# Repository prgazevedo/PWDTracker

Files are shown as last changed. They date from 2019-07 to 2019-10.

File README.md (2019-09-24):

# PWDTracker
A prototype for geo location using Lora

## Build - Current Build options

Requires following libraries:
 - PubsubClient for MQTT: https://github.com/knolleary/pubsubclient/releases/tag/v2.7
 - ArduinoJson for MQTT: https://arduinojson.org/?utm_source=meta&utm_medium=library.properties
 - Autoconnect for Wifi: https://hieromon.github.io/AutoConnect/index.html
 - TinyGpsPlus for GPS: https://github.com/mikalhart/TinyGPS
 - SSD1306 for OLED: https://github.com/ThingPulse/esp8266-oled-ssd1306
 - Lora radio by Sandeep: https://github.com/sandeepmistry/arduino-LoRa
 - MQTT by Joël Gähwiler: https://github.com/256dpi/arduino-mqtt
 - TLS-enabled web server for the ESP32 using the Arduino core: https://github.com/fhessel/esp32_https_server
  - SimpleList: https://github.com/blackhack/ArduLibraries/tree/master/SimpleList
Board library:
 - Heltec: https://github.com/HelTecAutomation/Heltec_ESP32
For low power uses: https://github.com/espressif/esp-idf/blob/master/components/esp32/include/esp_sleep.h
In _Definitions.h change _ROLE to either 0 or 1 //SENDER=0 RECEIVER=1

## Upload Current Bin files
 - See binary files to upload to modules in [PWDTracker/bin](https://github.com/prgazevedo/PWDTracker/tree/master/bin)
 - Note: to upload: 1- turn on verbose output (in Preferences). 2- Make a dummy arduino file and during upload and watch for a command in the end with AVRDUDE in it along with the path of hex/bin file. 3- just copy paste & run the same command in CommandLine replacing the bin file with the one downloaded from here.

## Current Used Hardware
- Upload this code via Serial to Heltec Wifi Lora: https://heltec.org/project/wifi-lora-32/ can buy it here: https://www.amazon.es/gp/product/B076T28KWG
- Use a GPS module to connect (Rx<-->TX) to pins 22/23 on Heltec: Rx-Heltec_Pin22 to Tx pin on GPS and Rx-Heltec_Pin23 to  Rx pin on GPS . ![GPS connectors] (https://github.com/prgazevedo/PWDTracker/blob/master/images/GT-U7_connections_back.png)
Buy similar GPS modules at: https://www.aliexpress.com/item/32828934753.html or https://www.amazon.es/gp/product/B0783H7BLW
An example of soldering connections for GPS to Heltec module is
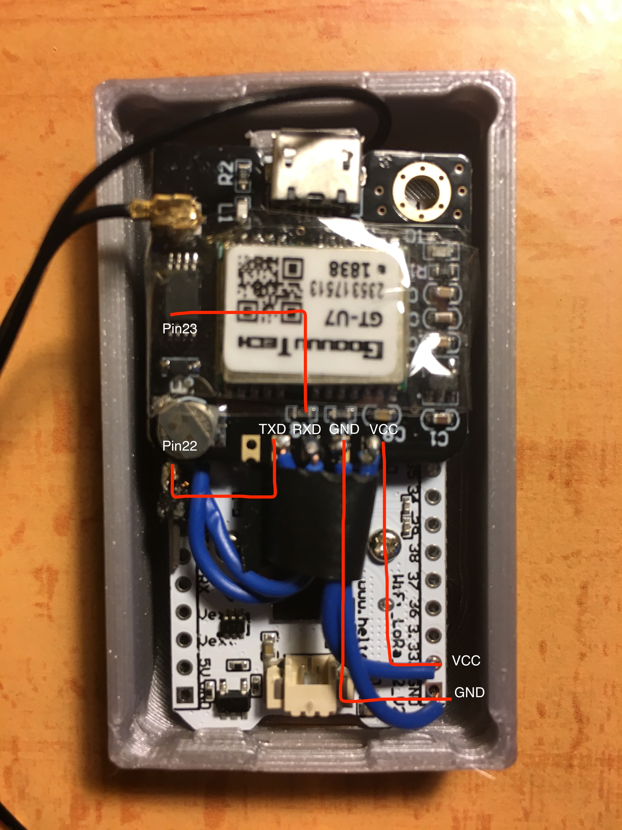
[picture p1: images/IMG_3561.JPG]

- Use ipex connector for Lora devices(DO NOT POWER UP WITHOUT ANTENNA CONNECTED)
- Use a good GPS antenna for precision outdoors: https://www.amazon.es/gp/product/B01BML4XMQ
- Use a Ipex to SMA converter: https://www.amazon.es/gp/product/B07G5H6WH3
- Use the following batteries to Sender (Li-Po 3.7V 850mAh 6x30x48mm):https://mauser.pt/catalog/product_info.php?products_id=035-9016 and Receiver (Li-Po 3.7V 450mAh 5x22x48mm): https://mauser.pt/catalog/product_info.php?products_id=035-9008
- Connect the batteries and the Switch to Heltec Raster PicoBlade connector: https://mauser.pt/catalog/product_info.php?products_id=035-0050
- Solder the + contact of the battery and of Heltec connector to the switch: https://mauser.pt/catalog/product_info.php?products_id=010-1218
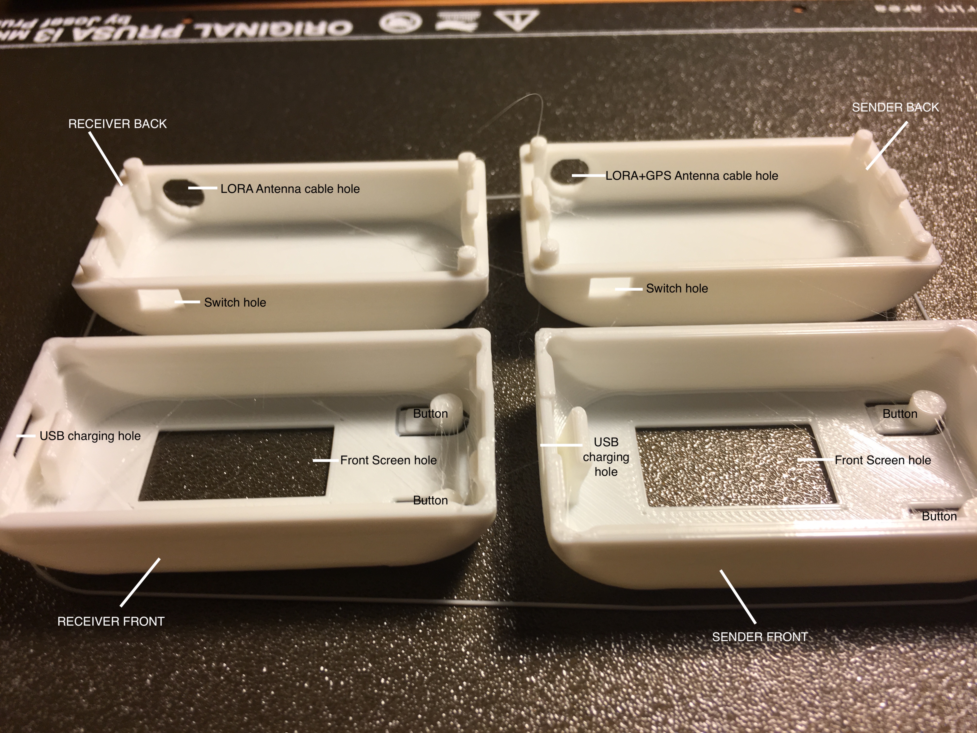
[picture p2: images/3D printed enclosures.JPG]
printed enclosures
- 3d print the enclosures using the files at (https://github.com/prgazevedo/PWDTracker/tree/master/enclosures). An example of the printed enclosures is 
An example of the full setup is
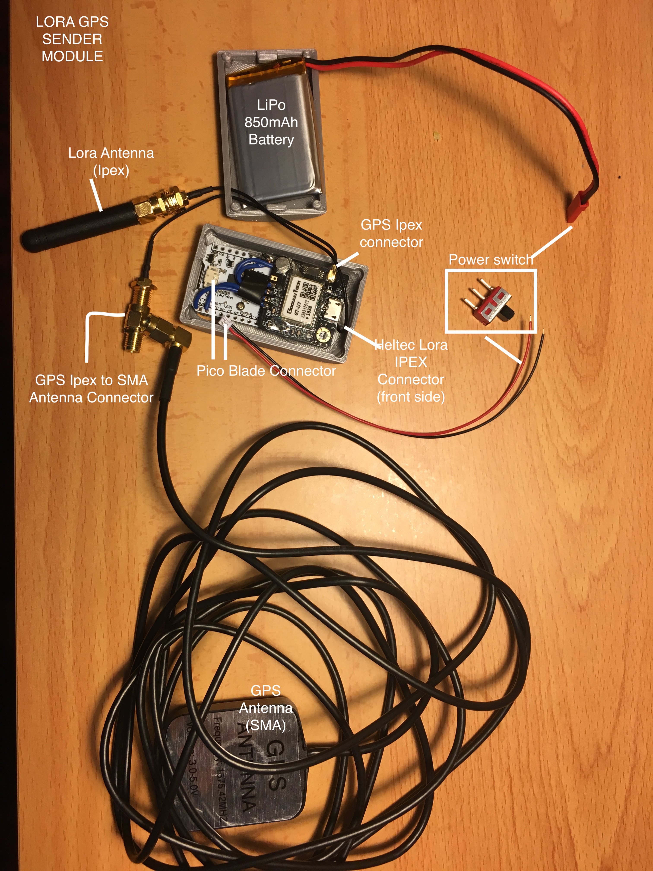
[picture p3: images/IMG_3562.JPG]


## Current Usage
 - Power up both devices (power to all via USB)
 - Check that both devices boot up and present correct GPS data in OLED display
 - Connect to receiver IP via http to view the location of sender device
 - View latitude and longitude of sender in the cloud: mqtt://broker.hivemq.com:1883 Topic:owntracks/PWD/#
 - Download the App at AppStore(https://apps.apple.com/us/app/owntracks/id692424691) or GooglePlay (https://play.google.com/store/apps/details?id=org.owntracks.android&hl=en)

## TODO
 - ~~Add webserver to configure options~~ (DONE)
 - Add discovery of wireless LAN tracking
 - Remove all String usage (avoid) and use CString or Char*
 - Optimize Sender code to reduce power consumption
 - Setup and test autoconnect functionality in Receiver

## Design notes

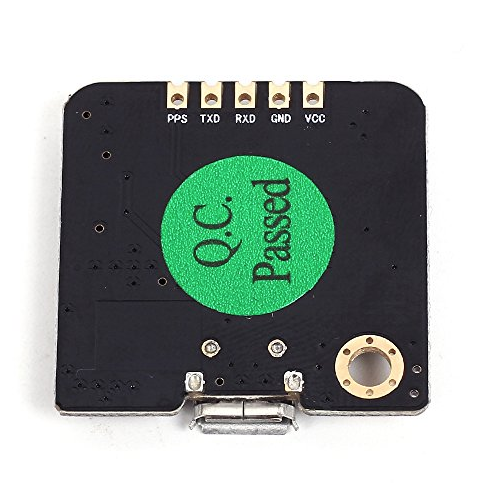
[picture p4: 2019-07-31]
images/GT-U7_connections_back.png

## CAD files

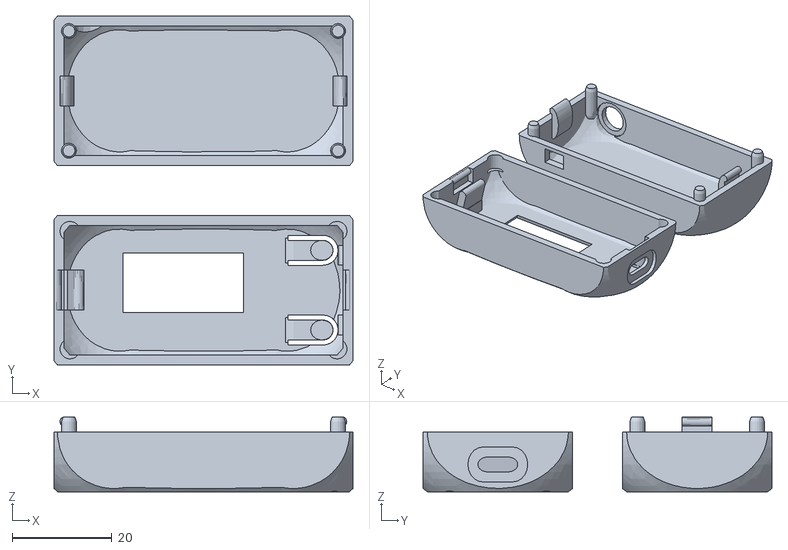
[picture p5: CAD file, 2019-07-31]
enclosures/Lora-Proto-with_switch_receiver_v1.stl
60.0 x 70.0 x 15.0

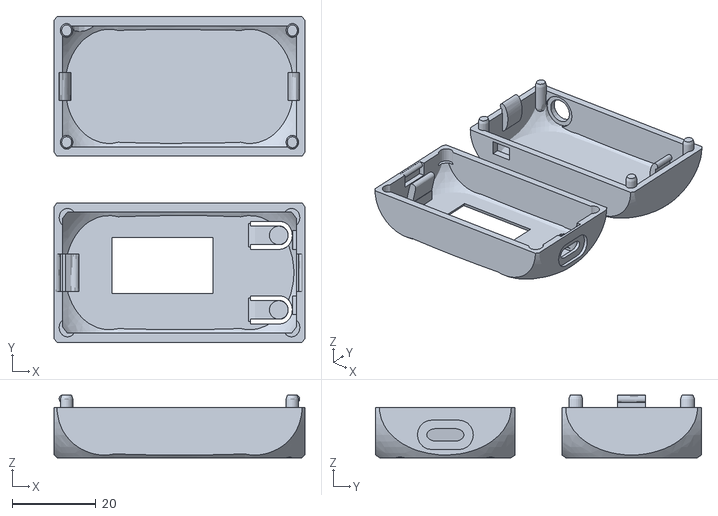
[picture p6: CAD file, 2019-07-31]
enclosures/Lora-Proto-with_switch_sender_v1.stl
60.0 x 78.0 x 15.0

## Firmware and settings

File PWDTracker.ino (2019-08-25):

/*
 * Copyright 2018 Pedro Azevedo (prgazevedo@gmail.com)
 * and other contributors as indicated by the @author tags.
 * 
 * Based on: 
 * https://github.com/mikalhart/TinyGPSPlus
 * https://github.com/Heltec-Aaron-Lee/WiFi_Kit_series
 * https://github.com/sandeepmistry/arduino-LoRa
 **********************************************************************
 * Licensed under the Apache License, Version 2.0 (the "License");
 * you may not use this file except in compliance with the License.
 * You may obtain a copy of the License at
 *
 *    http://www.apache.org/licenses/LICENSE-2.0
 *
 * Unless required by applicable law or agreed to in writing, software
 * distributed under the License is distributed on an "AS IS" BASIS,
 * WITHOUT WARRANTIES OR CONDITIONS OF ANY KIND, either express or implied.
 * See the License for the specific language governing permissions and
 * limitations under the License.
 */

#include <SPI.h> //Serial Comms Lib
#include <LoRa.h> //Lora Comms Lib
#include "SSD1306.h" //OLED display Lib
#include "_CStrings.h" //CString mem reduction code
#include "_SerialCode.h" //Serial lib
#include "_oledCode.h" //OLED code
#include "_GPSCode.h" //GPS code
#include "_LoraCode.h" //Lora Code
#include "_Definitions.h"
#include "_Global.h"
#include "_WifiManager.h"
#include "_File.h"
#include "_MQTT.h"
#include "_httpServer.h"
#include "_lowPower.h"



void setup()
{
  writeSerial("PWD setup Begin");
  //LED CFG
  pinMode(25,OUTPUT);
  _SerialInit();
  _OledInit();
  _LoraInit();
  _setupMAC();
  _Fileinit();
  writeSerial(_readPassword());
  _setupPower();
  #if _ROLE == 0
   writeSerial("setup Sender called");
    
    // Setup the GPS
    _SetupGPS();
    // Setup lower CPU frequency
    _switch_freq(CPU_FREQ);
  #endif
  #if _ROLE == 1
      // only compile MQTT if in receiver mode
      writeSerial("setup Receiver called");
      //_setupWifiConnection();
      
      _setupAutoconnect();

      _connectMQTTServer();
      //_setupWebServer();
      _setupHTTPSSERVER();
      OLED_write("Waiting for LORA Packets");
  #endif

  writeSerial("setup Ended");

}



void loop()
{ 
  if(_readPowerTimer()){
    _readBatteryPower();
  }
  if(_ROLE==0)
  {
     //_light_sleep();

     //_LEDBlink(); //SAVE POWER
     if (_sendTimer()){  
          
        _getGPS();
        _Send();
      }


  }
  else
  {
    //_ROLE==RECEIVER
    _Receive();
    if(_receiveTimer())
    {
      Serial.println("MQTT  _publishLocationData called"); 
       _publishLocationData();
    }
    if(_checkhttpserverTimer())
    {
      
      if(bPortalStarted){
        Serial.println("_handlePortal called"); 
        _handlePortal();
      }
      else {
        Serial.println("_httpServerLoop called"); 
        _updateWifiState();
        //_checkWifiState();
        
        _httpServerLoop();
      }

    }
    _LEDBlink();
    
  }

}

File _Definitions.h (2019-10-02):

#ifndef _CONST_H
#define _CONST_H

// _Main DEFINITIONS
// Possible roles SENDER or RECEIVER
#define _ROLE  1 //SENDER=0 RECEIVER=1
#define _SUBVERSION "20.1"

//POWER DEFINITIONS
#define BATTERY_PIN 13
#define _FULL_BATTERY    3700  //The default battery is 3700mv when the battery is fully charged.
#define _POWER_READ_INTERVAL 20000
#define CPU_FREQ 80 //160
#define CONFIG_ESP_CONSOLE_UART_NUM 1
//LOW POWER DEFINITIONS
#define uS_TO_S_FACTOR 1000000  /* Conversion factor for micro seconds to seconds */
#define TIME_TO_SLEEP  2       /* Time ESP32 will go to sleep (in seconds) */
//LORA DEFINITIONS
// LORA Pin definition
#define _SCK     5    // GPIO5  -- SX127x's SCK
#define _MISO    19   // GPIO19 -- SX127x's MISO
#define _MOSI    27   // GPIO27 -- SX127x's MOSI
#define _SS      18   // GPIO18 -- SX127x's CS
#define _RST     14   // GPIO14 -- SX127x's RESET
#define _DI00    26   // GPIO26 -- SX127x's IRQ(Interrupt Request)
//Interval in ms between sending data to other Lora
#define _LORA_SEND_INTERVAL 28518 //see here:https://www.loratools.nl/#/airtime
// LORA Band definition
#define _BAND    868E6  //Radio Frequency
#define _PABOOST true
#define _LONG_RANGE true
#define _MAXPOWER true
///LONG RANGE SETUP
#define _SIGNAL_BANDWIDTH 125E3
#define _SPREADING_FACTOR 8 
#define _CODING_RATE 7
#define _MAX_TX_POWER 14

//GPS DEFINITIONS
#define RXPin 22
#define TXPin 23
#define GPSBaud 9600
#define GPS_H_PRECISION 2.5 // from: https://www.u-blox.com/sites/default/files/products/documents/NEO-7_DataSheet_%28UBX-13003830%29.pdf
#define GPS_V_PRECISION 5 //double the horizontal - https://portal.u-blox.com/s/question/0D52p00008HKCDmCAP/does-ublox-standalone-positioning-provide-vertical-positioning-how-precise-is-it
//WIFI DEFINITIONS
//network SSID
#define _WIFI_MODE WIFI_AP_STA   //Alternatives 
#define _SSID_NAME "PWD"
#define _SSID_PASSWORD "pwdteste"
#define _SSID_CONNECT_TIMER 30000
#define _PORTAL_TIMER 180000
//EEPROM Settings
#define CREDENTIAL_OFFSET 0

//WEBSERVER
#define HTTP_PORT 80
#define _WEBSERVER_INTERVAL 1500

//OLED LOGO DEFINITIONS
#define FRAME_DELAY 500 
#define LOGO_DELAY 5000 

//MQTT DEFINITIONS
//Server MQTT 
#define MQTT_SERVER "broker.hivemq.com"
#define MQTT_SERVER_PORT 1883
#define MQTT_MESSAGE_SIZE 256
//Name of the topic to send data
#define TOPIC_NAME_HEADER "owntracks/PWD/TEST"

#endif

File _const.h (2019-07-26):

#ifndef _CONST_H
#define _CONST_H

// _MainVar
// Possible roles SENDER or RECEIVER
#define _ROLE  1 //SENDER=0 RECEIVER=1
#define _SUBVERSION "14"

//LORA DEFINITIONS
// LORA Pin definition
#define _SCK     5    // GPIO5  -- SX127x's SCK
#define _MISO    19   // GPIO19 -- SX127x's MISO
#define _MOSI    27   // GPIO27 -- SX127x's MOSI
#define _SS      18   // GPIO18 -- SX127x's CS
#define _RST     14   // GPIO14 -- SX127x's RESET
#define _DI00    26   // GPIO26 -- SX127x's IRQ(Interrupt Request)
//Interval in ms between sending data to other Lora
#define _LORA_SEND_INTERVAL 1000
// LORA Band definition
#define _BAND    868E6  //Radio Frequency
#define _PABOOST true
#define _LONG_RANGE false
///LONG RANGE SETUP
#define _SIGNAL_BANDWIDTH 10.4E3
#define _SPREADING_FACTOR 7 
#define _CODING_RATE 8
#define _TX_POWER 18

//GPS DEFINITIONS
static const int RXPin = 22, TXPin = 23;
static const uint32_t GPSBaud = 9600;


//Time of last Lora data packet
long lastSendTime = 0;



//LORA data struct to send
typedef struct {
  unsigned int ID;
  long timeMillis;
}PacketData;
PacketData pdata;

//LORA packet data
int rssi_value = 0;
unsigned long snr_value = 0;
String packSize = "--";
int payload_pdata_size = 0;
int payload_gdata_size = 0;
byte destinationAddress = 0xFF;      // destination to send to 11111111
byte localAddress = 0x01;     // address of this device 00000001
byte packetID = 0;            // count of outgoing messages
long time_stamp = 0;        // last send time
//WIFI DEFINITIONS
//network SSID
#define _WIFI_MODE WIFI_AP_STA   //Alternatives 
#define _SSID_NAME "WLAN2"
#define _SSID_PASSWORD "pedro2chave2"
#define _WIFI_WAIT 500
#define _WIFI_STATUS_TIMER 5000
#define _WIFI_RETRIES  15
#define _WIFI_TIMEOUT 3
#define _WEBSERVER_INTERVAL 1500
//WIFI
boolean WIFI_CONNECTION = false;
String WIFI_IP_STR = "Not Connected";


//OLED DEFINITIONS
//parameters: address,SDA,SCL 
SSD1306 display(0x3c, 4, 15); //display object 
#define FRAME_DELAY 500 
#define LOGO_DELAY 5000 



String g_latitude ="";
String g_longitude ="";

#endif

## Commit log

2019-06-25 V10 +correct coord
    V10 +correct coord
    [_const.h]
2019-07-31 Add 3d enclosure files
    Add 3d enclosure files
    [Lora-Proto-with_switch_receiver_v1.stl, Lora-Proto-with_switch_sender_v1.stl]
2019-07-31 Assembly images
    Assembly images
2019-07-31 3d enclosures
